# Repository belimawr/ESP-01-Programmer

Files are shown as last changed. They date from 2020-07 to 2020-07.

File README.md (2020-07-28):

# ESP-01 Programmer

This programmer needs a external 3.3V, 0.5A power supply. The VCC pin
of the FTDI board is not connected because it can happen that the
current it can supply is not enough in some cases, leading to a
unstable behaviour.

## Schematic:


The RESET function/pin is not working in any of my breakout
boards. According to the
[Datasheet](https://www.espressif.com/sites/default/files/documentation/0a-esp8266ex_datasheet_en.pdf)
the RESET pin is active low, but it is not working on my breakout
boards. The workaround I found is to power-cycle the board every time
a reset is needed (including programming).

## Board library for Arduino IDE (1.8.13) programming

[esp8266/Arduino](https://github.com/esp8266/Arduino)
## Programming
Set the board parameters according to this picture:

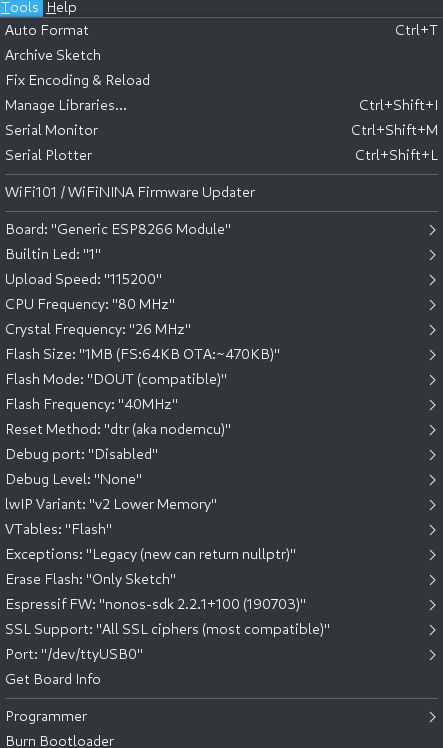
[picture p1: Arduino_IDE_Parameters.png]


Short the jumnper (JP1), hit "upload" then power-cycle the board. The
upload should run smoothly. If it does not, activate verbose output
for upload, then when you see this line:

`Connecting........_____`

Power-cycle the board again.

## Using I2C

The I2C bus uses `GPIO0` and `GPIO2`, those pins are available
on J3 and J4. To enable I2C on those pins, use `Wire.begin(0, 2);`.

[i2c_scanner.ino](i2c_scanner.ino) is an i2c scanner that shows how to
use the I2C bus on this board.

## Files

* [Schematic (PDF)](ESP01-Programmer.pdf)
* [3D board view](ESP01-Programmer_3D.png) - That is just a reference
  to help assembling on a prefboard
* [Kicad files](Kicad)

## Other resources
* [ESP-01 cheat
  sheet](esp8266_esp_01_module_pinout_diagram_cheat_sheet_by_adlerweb.png)
* [ESP-01 Manual](http://www.microchip.ua/wireless/esp01.pdf) - There
  is a schematic at the end
* [ESP-01 example applications](https://www.forward.com.au/pfod/ESP8266/GPIOpins/ESP8266_01_pin_magic.html)

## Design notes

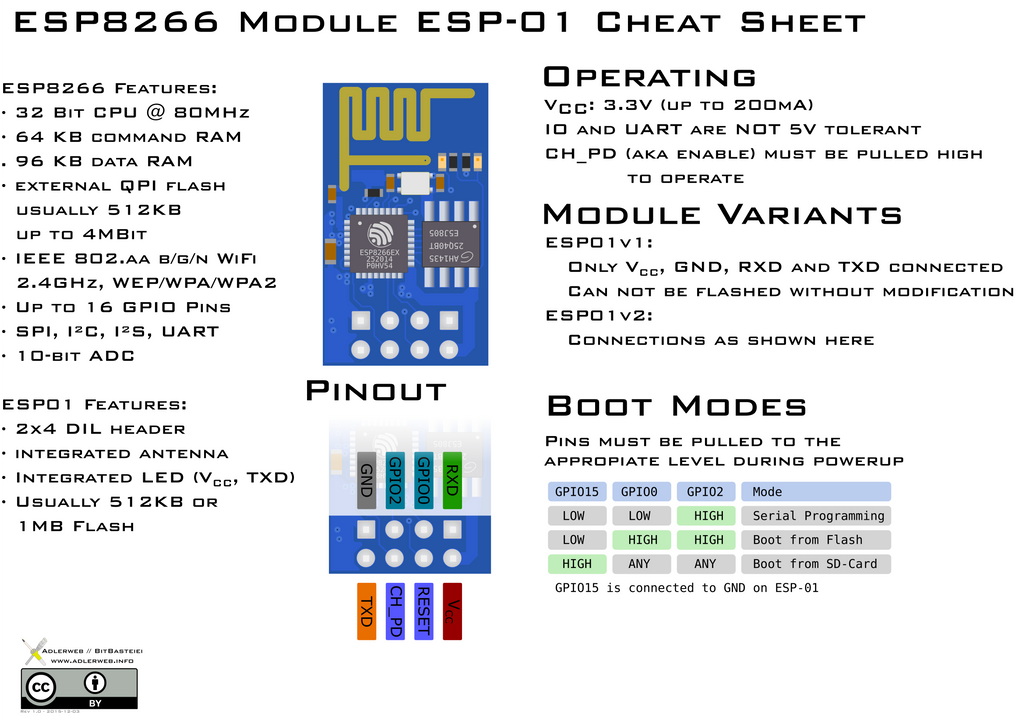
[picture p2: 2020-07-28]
esp8266_esp_01_module_pinout_diagram_cheat_sheet_by_adlerweb.png

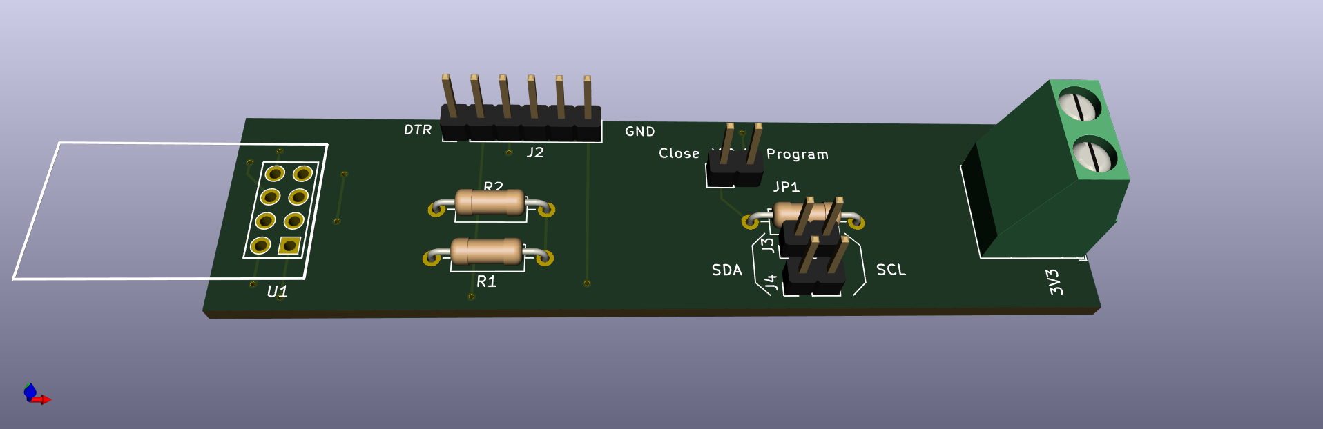
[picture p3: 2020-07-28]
ESP01-Programmer_3D.png

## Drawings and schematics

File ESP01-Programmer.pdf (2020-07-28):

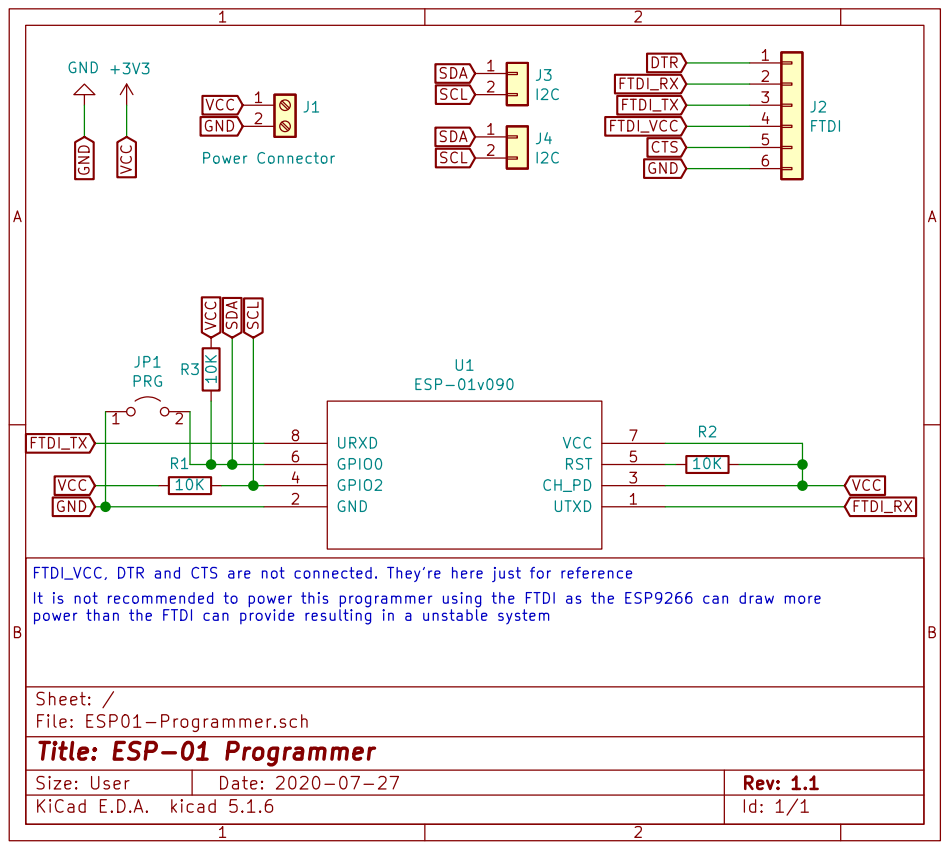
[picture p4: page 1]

FTDI_VCC, DTR and CTS are not connected. They're here just for reference
It is not recommended to power this programmer using the FTDI as the ESP9266 can draw more
power than the FTDI can provide resulting in a unstable system

File: ESP01-Programmer.sch Sheet: /
Id: 1/1 Title: ESP-01 Programmer

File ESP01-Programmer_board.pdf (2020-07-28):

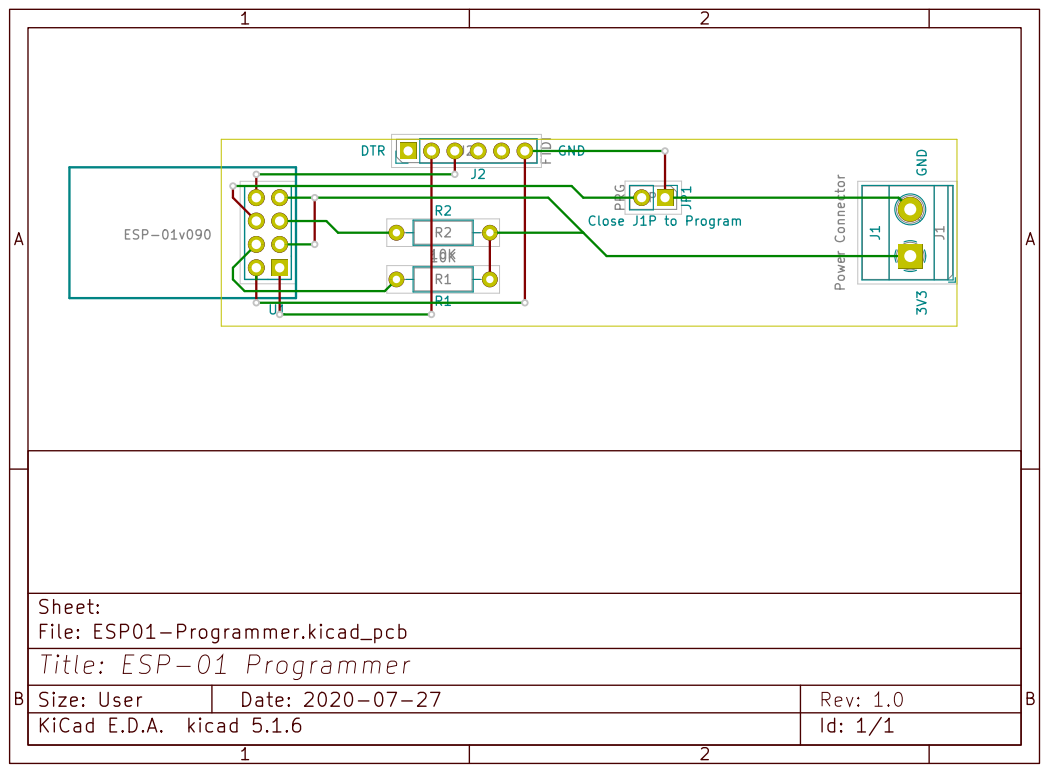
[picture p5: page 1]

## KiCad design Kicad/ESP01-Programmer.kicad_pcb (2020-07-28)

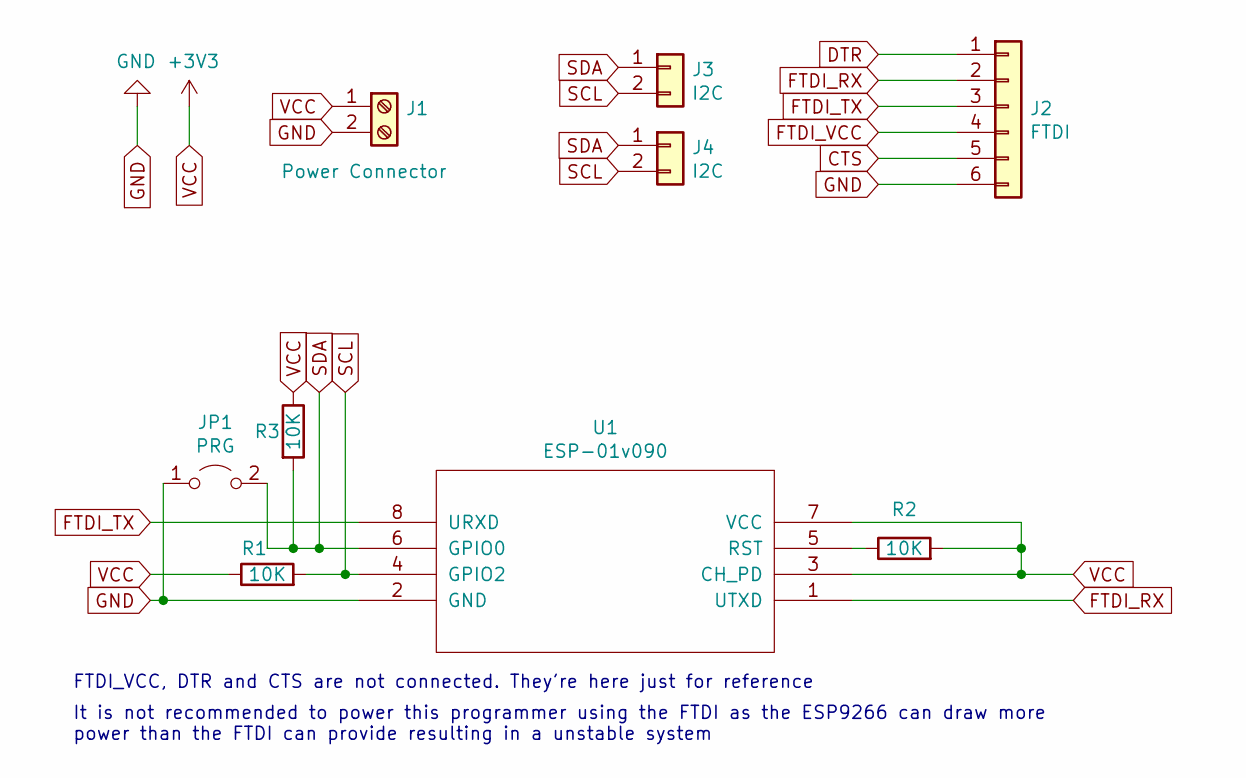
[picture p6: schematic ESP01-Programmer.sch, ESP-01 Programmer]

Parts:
J1: Power Connector; TerminalBlock_Phoenix_MKDS-1,5-2-5.08_1x02_P5.08mm_Horizont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
J2: FTDI; PinHeader_1x06_P2.54mm_Vertical
J3, J4: I2C; PinHeader_1x02_P2.54mm_Vertical
JP1: PRG; PinHeader_1x02_P2.54mm_Vertical
R1, R2, R3: 10K; R_Axial_DIN0207_L6.3mm_D2.5mm_P10.16mm_Horizontal
U1: ESP-01v090; ESP-01

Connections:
CTS: J2.5
DTR: J2.1
FTDI_RX: J2.2, U1.1 (UTXD)
FTDI_TX: J2.3, U1.8 (URXD)
FTDI_VCC: J2.4
GND: J1.2, J2.6, JP1.1 (A), U1.2 (GND)
unnamed: R2.1, U1.5 (RST)
SCL: J3.2, J4.2, R1.2, U1.4 (GPIO2)
SDA: J3.1, J4.1, JP1.2 (B), R3.2, U1.6 (GPIO0)
VCC: J1.1, R1.1, R2.2, R3.1, U1.3 (CH_PD), U1.7 (VCC)

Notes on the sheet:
FTDI_VCC, DTR and CTS are not connected. They're here just for reference
It is not recommended to power this programmer using the FTDI as the ESP9266 can draw more power than the FTDI can provide resulting in a unstable system

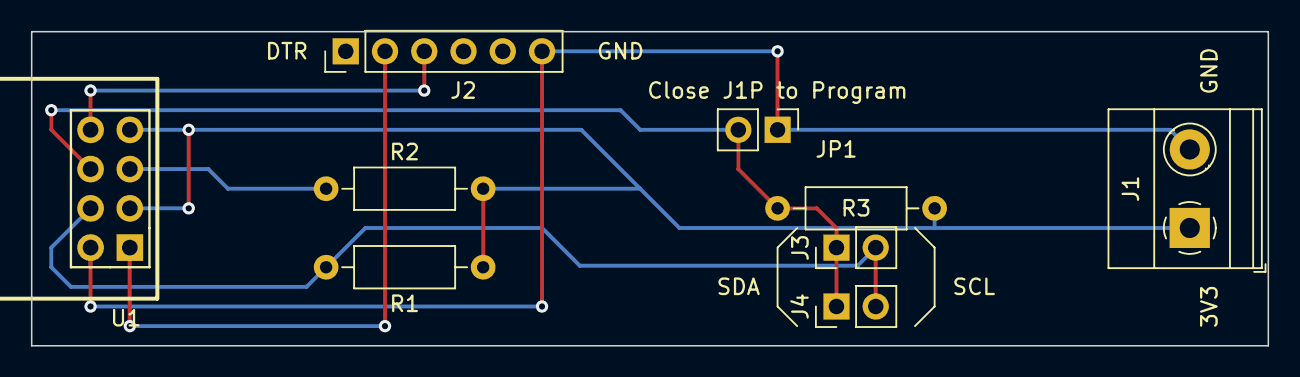
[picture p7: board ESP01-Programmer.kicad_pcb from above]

Board: 2 copper layers, 80.0 x 20.3 mm, 9 parts (0 on the bottom side), 7 nets.

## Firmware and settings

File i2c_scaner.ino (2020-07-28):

// --------------------------------------
// i2c_scanner
//
// Version 1
//    This program (or code that looks like it)
//    can be found in many places.
//    For example on the Arduino.cc forum.
//    The original author is not know.
// Version 2, Juni 2012, Using Arduino 1.0.1
//     Adapted to be as simple as possible by Arduino.cc user Krodal
// Version 3, Feb 26  2013
//    V3 by louarnold
// Version 4, March 3, 2013, Using Arduino 1.0.3
//    by Arduino.cc user Krodal.
//    Changes by louarnold removed.
//    Scanning addresses changed from 0...127 to 1...119,
//    according to the i2c scanner by Nick Gammon
//    https://www.gammon.com.au/forum/?id=10896
// Version 5, March 28, 2013
//    As version 4, but address scans now to 127.
//    A sensor seems to use address 120.
// Version 6, November 27, 2015.
//    Added waiting for the Leonardo serial communication.
//
// Version 7, July 28 2020.
//    Using configurable pins I2C pins for compatibility with
//    ESP8266 - (ESP-01 board)
//
// This sketch tests the standard 7-bit addresses
// Devices with higher bit address might not be seen properly.
//
 
#include <Wire.h>

#define SDA 0
#define SCL 2
 
void setup()
{
  Wire.begin(SDA, SCL);
 
  Serial.begin(115200);
  while (!Serial); // Leonardo: wait for serial monitor
  Serial.println("\nI2C Scanner");
}
 
 
void loop()
{
  byte error, address;
  int nDevices;
 
  Serial.println("Scanning...");
 
  nDevices = 0;
  for(address = 1; address < 127; address++ )
  {
    // The i2c_scanner uses the return value of
    // the Write.endTransmisstion to see if
    // a device did acknowledge to the address.
    Wire.beginTransmission(address);
    error = Wire.endTransmission();
 
    if (error == 0)
    {
      Serial.print("I2C device found at address 0x");
      if (address<16)
        Serial.print("0");

      Serial.print(address, HEX);
      Serial.println("  !");
 
      nDevices++;
    }
    else if (error==4)
    {
      Serial.print("Unknown error at address 0x");
      if (address<16)
        Serial.print("0");

      Serial.println(address,HEX);
    }
  }

  if (nDevices == 0)
    Serial.println("No I2C devices found\n");
  else
    Serial.println("done\n");
 
  delay(5000); // wait 5 seconds for next scan
}

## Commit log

2020-07-28 V1.0: First working version
    [ESP01-Programmer.kicad_pcb, ESP01-Programmer.sch]
2020-07-28 V1.1: Adding I2C bus headers.
    More information and resources are also added.
    [ESP01-Programmer.kicad_pcb, ESP01-Programmer.sch]
